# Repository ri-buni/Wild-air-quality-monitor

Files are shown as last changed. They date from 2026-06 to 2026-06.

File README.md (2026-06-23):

# Wild-air-quality-monitor
An air quality monitor I've decided to make because of how bad the air in my city can be sometimes.
It has sht41, sgp40, scd41, PMS5003 as sensors for temperature, humidity, VOC CO2 and PM, 2"42 display and esp32 devkitc

# CAD
Made in Fusion360.

anydesk00012

anydesk00011

anydesk00013

# PCB
Made in KiCad.

Schematic:

anydesk00009

PCB:

anydesk00010

# Firmware was made by Claude Code

Display looks like this:

Screenshot (24)

# BOM

| Item | Description | Qty | Unit Price | Line Total | Source |
|---|---|---|---|---|---|
| PCB | Custom 2-layer PCB | 1 | $12.00 | $12.00 | [JLCPCB](https://jlcpcb.com/) |
| ESP32-S3 DevKitC | MCU dev board | 1 | $5.00 | $5.00 | [AliExpress](https://aliexpress.ru/item/1005007820190456.html?sku_id=12000058365460928) |
| 2.42" OLED | 128x64 SSD1309, I2C/SPI | 1 | $12.00 | $12.00 | [AliExpress](https://aliexpress.ru/item/4000002579405.html?sku_id=12000037978104081) |
| SGP40 | VOC gas sensor module | 1 | $5.00 | $5.00 | [AliExpress](https://aliexpress.ru/item/1005008380047927.html?sku_id=12000056592935021) |
| SCD41 | CO2 + temp/humidity sensor | 1 | $14.00 | $14.00 | [AliExpress](https://aliexpress.ru/item/1005010621571588.html?sku_id=12000053002326414) |
| SHT41 | Temp/humidity sensor | 1 | $1.50 | $1.50 | [AliExpress](https://aliexpress.ru/item/1005008842184215.html?sku_id=12000057743184144) |
| Li-ion battery | 500mAh 3.7V (502535) | 1 | $5.10 | $5.10 | [AliExpress](https://aliexpress.ru/item/1005006462526013.html?sku_id=12000037283411655) |
| TP4056 | Li-ion charger module | 1 | $0.50 | $0.50 | [AliExpress](https://aliexpress.ru/item/32453058256.html?sku_id=12000052763412620) |
| PMS5003 | Laser PM2.5 sensor | 1 | $13.20 | $13.20 | [AliExpress](https://aliexpress.ru/item/32772775425.html?sku_id=12000027208101193) |
| **GRAND TOTAL** |  |  |  | **$68.30** |  |

# Details:

I've used this tutorial as a reference: https://howtomechatronics.com/projects/diy-air-quality-monitor-pm2-5-co2-voc-ozone-temp-hum-arduino-meter/

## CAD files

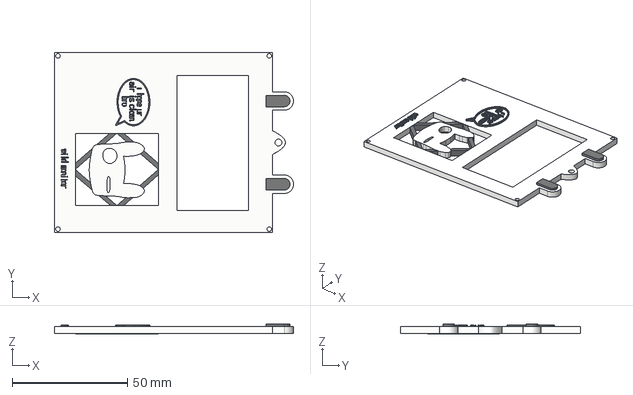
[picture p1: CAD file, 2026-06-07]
Production/TopPart wild monitor.step
103.5 x 78.0 x 4.40 mm

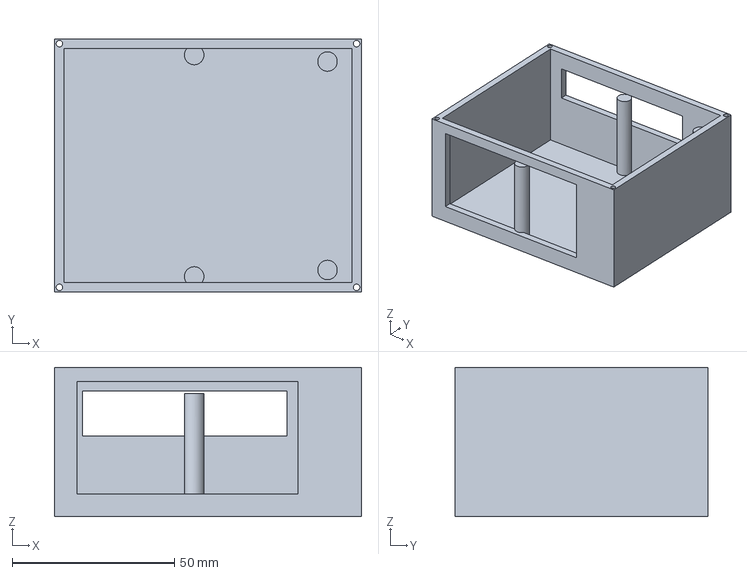
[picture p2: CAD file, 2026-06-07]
Production/BottomPart wild monitor.step
94.5 x 78.0 x 46.0 mm

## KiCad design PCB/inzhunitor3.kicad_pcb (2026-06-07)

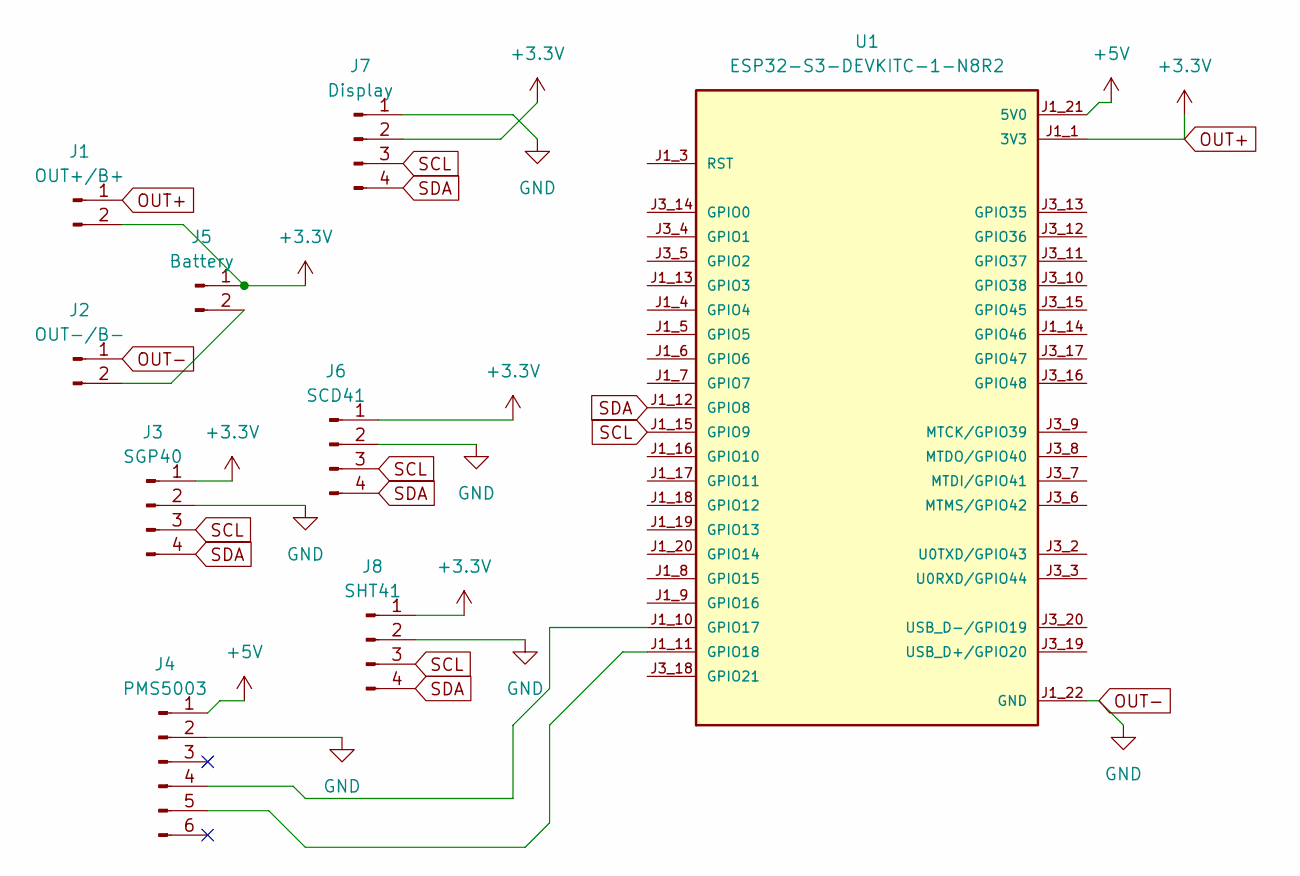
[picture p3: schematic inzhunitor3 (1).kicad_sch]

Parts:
J1: OUT+/B+; PinHeader_1x02_P2.54mm_Vertical
J2: OUT-/B-; PinHeader_1x02_P2.54mm_Vertical
J3: SGP40; PinHeader_1x04_P2.54mm_Vertical
J4: PMS5003; PinHeader_1x06_P2.54mm_Vertical
J5: Battery; PinHeader_1x02_P2.54mm_Vertical
J6: SCD41; PinHeader_1x04_P2.54mm_Vertical
J7: Display; PinHeader_1x04_P2.54mm_Vertical
J8: SHT41; PinHeader_1x04_P2.54mm_Vertical
U1: ESP32-S3-DEVKITC-1-N8R2; XCVR_ESP32-S3-DEVKITC-1-N8R2; PARTREV V1

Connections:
+5V: J4.1, U1.J1_21 (5V0)
unnamed: J2.2, J5.2
unnamed: J4.4, U1.J1_10 (GPIO17)
unnamed: J4.5, U1.J1_11 (GPIO18)
OUT+: J1.1, J1.2, J3.1, J5.1, J6.1, J7.2, J8.1, U1.J1_1 (3V3), U1.J1_2 (3V3)
OUT-: J2.1, J3.2, J4.2, J6.2, J7.1, J8.2, U1.J1_22 (GND), U1.J3_1 (GND), U1.J3_21 (GND), U1.J3_22 (GND)
SCL: J3.3, J6.3, J7.3, J8.3, U1.J1_15 (GPIO9)
SDA: J3.4, J6.4, J7.4, J8.4, U1.J1_12 (GPIO8)

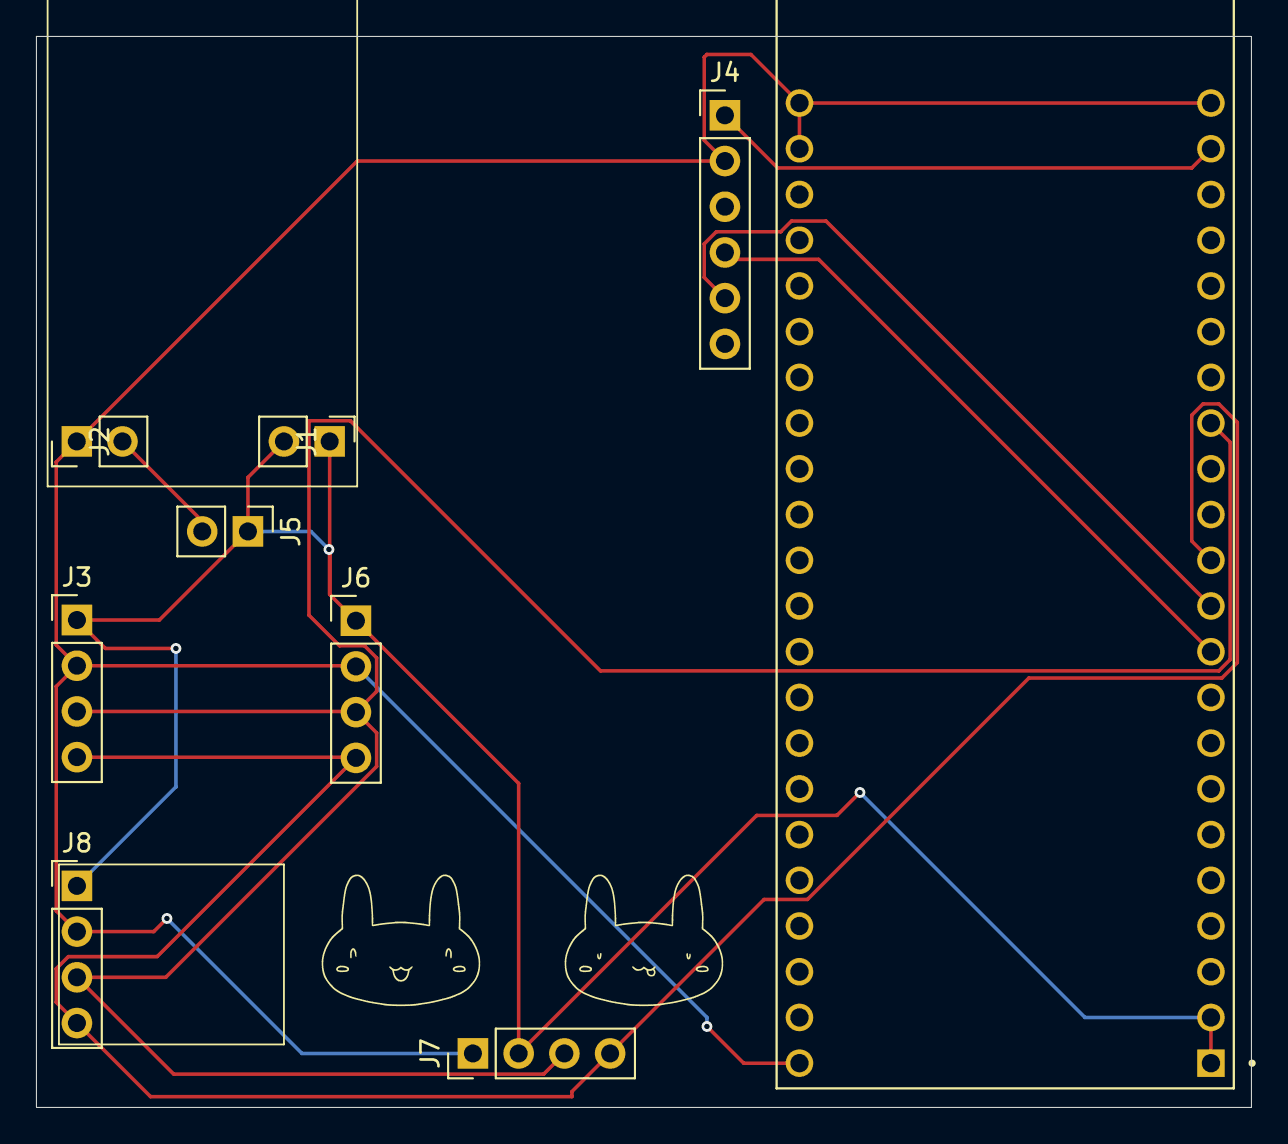
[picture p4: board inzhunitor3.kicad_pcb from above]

Board: 2 copper layers, 67.5 x 59.5 mm, 9 parts (0 on the bottom side), 8 nets.

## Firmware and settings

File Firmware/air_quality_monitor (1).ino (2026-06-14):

/*
 * Air Quality Monitor - ESP32-S3 DevKitC
 * ---------------------------------------
 * SCD41   -> CO2
 * SHT41   -> Temperature / Humidity (also feeds SGP40 compensation)
 * SGP40   -> VOC Index (via Sensirion Gas Index Algorithm)
 * PMS5003 -> PM1.0 / PM2.5 / PM10 (UART, NOT I2C)
 * Display: SSD1306/SSD1309 128x64 OLED over I2C
 * Power: TP4056 + Li-ion (charging handled by TP4056 hardware)
 *
 * Libraries (Arduino Library Manager):
 *   - Sensirion I2C SCD4x
 *   - Sensirion I2C SHT4x
 *   - Sensirion I2C SGP40
 *   - Sensirion Gas Index Algorithm
 *   - U8g2
 *
 * Wiring (I2C): SCD41 / SHT41 / SGP40 / OLED share one bus.
 *   SDA = GPIO8, SCL = GPIO9 (ESP32-S3 DevKitC defaults)
 *   Addresses: SCD41 0x62 | SHT41 0x44 | SGP40 0x59 | OLED 0x3C
 *
 * Wiring (PMS5003 UART, 5V VCC, 3.3V logic - safe for ESP32-S3 RX):
 *   PMS5003 TX (pin 5) -> ESP32 GPIO17 (PMS_RX)
 *   PMS5003 RX (pin 4) -> ESP32 GPIO18 (PMS_TX, optional - for sleep/wake cmds)
 *   PMS5003 VCC -> 5V    GND -> GND
 *   SET / RESET left floating (internal pull-ups keep the sensor running)
 */

#include <Arduino.h>
#include <Wire.h>
#include <U8g2lib.h>
#include <SensirionI2cScd4x.h>
#include <SensirionI2cSht4x.h>
#include <SensirionI2CSgp40.h>
#include <VOCGasIndexAlgorithm.h>

// ---------- I2C pins (ESP32-S3 DevKitC defaults) ----------
#define I2C_SDA 8
#define I2C_SCL 9

// ---------- PMS5003 UART (Serial1) ----------
#define PMS_RX  17   // <- PMS5003 TX
#define PMS_TX  18   // -> PMS5003 RX (optional)
#define PMS_BAUD 9600
#define PMS_FRAME_LEN 32
HardwareSerial PmsSerial(1);

// ---------- Sampling ----------
const uint32_t SAMPLE_INTERVAL_MS = 1000;   // SGP40 must be fed at a CONSTANT 1 Hz
const float    DEFAULT_TEMP_C     = 25.0f;
const float    DEFAULT_RH         = 50.0f;

// ---------- Objects ----------
U8G2_SSD1306_128X64_NONAME_F_HW_I2C u8g2(U8G2_R0, U8X8_PIN_NONE);
// For a true SSD1309 panel, swap the line above for:
// U8G2_SSD1309_128X64_NONAME0_F_HW_I2C u8g2(U8G2_R0, U8X8_PIN_NONE);

SensirionI2cScd4x scd41;
SensirionI2cSht4x sht41;
SensirionI2CSgp40 sgp40;
VOCGasIndexAlgorithm vocAlgorithm;   // default 1 Hz sampling interval

// ---------- Shared state ----------
float    g_temp = DEFAULT_TEMP_C;
float    g_rh   = DEFAULT_RH;
uint16_t g_co2  = 0;
int32_t  g_voc  = 0;
uint16_t g_pm1  = 0;   // PM1.0  (ug/m3, atmospheric)
uint16_t g_pm25 = 0;   // PM2.5  (ug/m3, atmospheric)
uint16_t g_pm10 = 0;   // PM10   (ug/m3, atmospheric)
bool     g_scdReady = false;
bool     g_pmReady  = false;

uint32_t lastSample = 0;

// =====================================================================
//  Helpers
// =====================================================================
static void haltWithError(const char* msg) {
  Serial.println(msg);
  u8g2.clearBuffer();
  u8g2.setFont(u8g2_font_6x12_tf);
  u8g2.drawStr(0, 12, "Init error:");
  u8g2.drawStr(0, 28, msg);
  u8g2.sendBuffer();
  while (true) delay(1000);
}

// Status levels: 0 = noice, 1 = okei, 2 = nah, 3 = Xtreme
uint8_t co2Level(uint16_t c) {
  if (c == 0)    return 0;
  if (c < 800)   return 0;
  if (c < 1200)  return 1;
  if (c < 1600)  return 2;
  return 3;
}
uint8_t vocLevel(int32_t v) {
  if (v < 100) return 0;
  if (v < 200) return 1;
  if (v < 300) return 2;
  return 3;
}
// PM2.5 ug/m3, loosely following US EPA 24h AQI breakpoints
uint8_t pm25Level(uint16_t p) {
  if (p <= 12)  return 0;   // good
  if (p <= 35)  return 1;   // moderate
  if (p <= 55)  return 2;   // unhealthy for sensitive
  return 3;                 // unhealthy+
}
const char* levelWord(uint8_t lvl) {
  switch (lvl) { case 0: return "noice";  case 1: return "okei";
                 case 2: return "nah";    default: return "Xtreme"; }
}

// Map CO2 ppm -> bar fill width (0..maxw), range 400..1600 ppm
uint8_t co2BarWidth(uint16_t c, uint8_t maxw) {
  if (c < 400) c = 400;
  long w = (long)(c - 400) * maxw / 1200;
  if (w > maxw) w = maxw;
  return (uint8_t)w;
}

// ---------------------------------------------------------------------
// Bunny mascot (earless). Drawn from primitives in a ~22x26 box whose
// top-left is (x, y). The face is symmetric about its vertical center.
// Expression changes with the air-quality level:
//   0 noice  -> ^ ^ happy eyes, smile
//   1 okei   -> o o dot eyes, flat mouth
//   2 nah    -> closed eyes (— —), flat mouth
//   3 Xtreme -> x x eyes, frown
// All strokes use the current draw color (set to 1/white by caller).
void drawBunny(uint8_t x, uint8_t y, uint8_t lvl) {
  // Head: rounded box, vertically roomy since there are no ears
  uint8_t hx = x + 2, hy = y + 4, hw = 18, hh = 18;
  u8g2.drawRFrame(hx, hy, hw, hh, 5);

  // Symmetry axis of the head
  uint8_t cx = hx + hw / 2;        // center column
  uint8_t ey = hy + 7;             // eye row
  uint8_t eo = 4;                  // eye offset from center (mirrored)
  uint8_t lx = cx - eo;            // left eye center
  uint8_t rx = cx + eo;            // right eye center

  if (lvl == 0) {
    // ^ ^ happy eyes (mirrored chevrons)
    u8g2.drawLine(lx - 2, ey, lx, ey - 2);
    u8g2.drawLine(lx, ey - 2, lx + 2, ey);
    u8g2.drawLine(rx - 2, ey, rx, ey - 2);
    u8g2.drawLine(rx, ey - 2, rx + 2, ey);
  } else if (lvl == 1) {
    // round dot eyes
    u8g2.drawDisc(lx, ey - 1, 1);
    u8g2.drawDisc(rx, ey - 1, 1);
  } else if (lvl == 2) {
    // closed eyes: short horizontal lines
    u8g2.drawHLine(lx - 2, ey - 1, 5);
    u8g2.drawHLine(rx - 2, ey - 1, 5);
  } else {
    // x x eyes (mirrored)
    u8g2.drawLine(lx - 1, ey - 2, lx + 1, ey);
    u8g2.drawLine(lx - 1, ey, lx + 1, ey - 2);
    u8g2.drawLine(rx - 1, ey - 2, rx + 1, ey);
    u8g2.drawLine(rx - 1, ey, rx + 1, ey - 2);
  }

  // Nose (on the axis) + mouth (symmetric about the axis)
  uint8_t ny = hy + 12;
  u8g2.drawPixel(cx, ny);
  if (lvl == 0) {
    // smile
    u8g2.drawLine(cx - 3, ny + 1, cx, ny + 3);
    u8g2.drawLine(cx, ny + 3, cx + 3, ny + 1);
  } else if (lvl == 3) {
    // frown
    u8g2.drawLine(cx - 3, ny + 3, cx, ny + 1);
    u8g2.drawLine(cx, ny + 1, cx + 3, ny + 3);
  } else {
    // flat mouth, centered
    u8g2.drawHLine(cx - 2, ny + 2, 5);
  }
}

// =====================================================================
//  Sensor reads
// =====================================================================
void readSht41() {
  float t, rh;
  uint16_t err = sht41.measureHighPrecision(t, rh);
  if (!err) {
    g_temp = t;
    g_rh   = rh;
  }
}

void readScd41() {
  bool dataReady = false;
  if (scd41.getDataReadyStatus(dataReady) == 0 && dataReady) {
    uint16_t co2;
    float t, rh;   // SCD41 also reports T/RH; we keep only CO2 per the sensor split
    if (scd41.readMeasurement(co2, t, rh) == 0 && co2 != 0) {
      g_co2 = co2;
      g_scdReady = true;
    }
  }
}

void readSgp40() {
  // Convert SHT41 T/RH into SGP40 compensation ticks
  uint16_t rhTicks   = (uint16_t)((g_rh * 65535) / 100.0f + 0.5f);
  uint16_t tempTicks = (uint16_t)(((g_temp + 45) * 65535) / 175.0f + 0.5f);

  uint16_t sraw = 0;
  uint16_t err = sgp40.measureRawSignal(rhTicks, tempTicks, sraw);
  if (!err) {
    g_voc = vocAlgorithm.process((int32_t)sraw);
  }
}

// PMS5003 frame: 0x42 0x4D | len(2) | 13x uint16 data | checksum(2).
// We read non-blocking; the sensor streams a frame roughly every ~1 s in
// active mode. Returns true when a valid checksummed frame was parsed.
bool readPms5003() {
  bool gotFrame = false;
  // Drain whatever is buffered this tick; keep only the freshest valid frame.
  while (PmsSerial.available() >= PMS_FRAME_LEN) {
    // Sync to start byte 0x42
    if (PmsSerial.peek() != 0x42) { PmsSerial.read(); continue; }

    uint8_t buf[PMS_FRAME_LEN];
    if (PmsSerial.readBytes(buf, PMS_FRAME_LEN) != PMS_FRAME_LEN) break;
    if (buf[1] != 0x4D) continue;   // second header byte must be 0x4D

    // Verify checksum: sum of bytes [0..29] == bytes[30..31]
    uint16_t sum = 0;
    for (uint8_t i = 0; i < 30; i++) sum += buf[i];
    uint16_t chk = ((uint16_t)buf[30] << 8) | buf[31];
    if (sum != chk) continue;       // corrupt frame, skip

    // Atmospheric-environment concentrations (bytes 12..17)
    g_pm1  = ((uint16_t)buf[12] << 8) | buf[13];
    g_pm25 = ((uint16_t)buf[14] << 8) | buf[15];
    g_pm10 = ((uint16_t)buf[16] << 8) | buf[17];
    g_pmReady = true;
    gotFrame = true;
  }
  return gotFrame;
}

// =====================================================================
//  Display
// =====================================================================
void draw() {
  char buf[24];
  u8g2.clearBuffer();

  // ---- Header bar (white) with title + small status pill ----
  uint8_t overall = max(max(co2Level(g_co2), vocLevel(g_voc)), pm25Level(g_pm25));
  u8g2.setDrawColor(1);
  u8g2.drawBox(0, 0, 128, 14);

  u8g2.setFont(u8g2_font_logisoso16_tr);  // header in the logisoso family
  u8g2.setDrawColor(0);                    // black text on white bar
  u8g2.drawStr(3, 13, "ri's grade");

  // ---- Hero: bunny mascot + big status word ----
  u8g2.setDrawColor(1);
  drawBunny(2, 16, overall);

  const char* word = levelWord(overall);
  u8g2.setFont(u8g2_font_helvB14_tr);   // bold; "Xtreme" fits left of the value column
  u8g2.drawStr(28, 38, word);

  // ---- CO2 + PM2.5 as small labeled values on the right column ----
  u8g2.setFont(u8g2_font_5x8_tr);
  // CO2
  if (g_scdReady) snprintf(buf, sizeof(buf), "CO2 %u", g_co2);
  else            strcpy(buf, "CO2 --");
  u8g2.drawStr(127 - u8g2.getStrWidth(buf), 25, buf);
  // PM2.5
  if (g_pmReady)  snprintf(buf, sizeof(buf), "PM %u", g_pm25);
  else            strcpy(buf, "PM --");
  u8g2.drawStr(127 - u8g2.getStrWidth(buf), 35, buf);

  // ---- CO2 level bar with threshold ticks (800 / 1200 / 1600 ppm) ----
  u8g2.drawVLine(33, 44, 2);
  u8g2.drawVLine(64, 44, 2);
  u8g2.drawVLine(95, 44, 2);
  u8g2.drawFrame(0, 46, 128, 6);
  uint8_t bw = co2BarWidth(g_scdReady ? g_co2 : 0, 124);
  if (bw > 0) u8g2.drawBox(2, 48, bw, 2);

  // ---- Footer: temp | humidity | VOC ----
  u8g2.drawVLine(43, 54, 9);
  u8g2.drawVLine(85, 54, 9);

  // thermometer icon
  u8g2.drawVLine(4, 55, 5);
  u8g2.drawDisc(4, 61, 1);
  u8g2.setFont(u8g2_font_5x8_tr);
  snprintf(buf, sizeof(buf), "%.1f", g_temp);
  u8g2.drawStr(9, 62, buf);
  u8g2.drawStr(9 + u8g2.getStrWidth(buf), 62, "\xb0");  // degree

  // droplet icon
  u8g2.drawDisc(48, 60, 2);
  u8g2.drawTriangle(48, 55, 46, 59, 50, 59);
  snprintf(buf, sizeof(buf), "%.0f%%", g_rh);
  u8g2.drawStr(53, 62, buf);

  // VOC
  snprintf(buf, sizeof(buf), "VOC %ld", (long)g_voc);
  u8g2.drawStr(88, 62, buf);

  u8g2.sendBuffer();
}

// =====================================================================
//  Setup / Loop
// =====================================================================
void setup() {
  Serial.begin(115200);
  delay(200);

  Wire.begin(I2C_SDA, I2C_SCL);
  Wire.setClock(100000);   // 100 kHz is safe for all four devices

  // PMS5003 on UART1 (active mode by default - it just streams frames)
  PmsSerial.begin(PMS_BAUD, SERIAL_8N1, PMS_RX, PMS_TX);

  // Display splash
  u8g2.begin();
  u8g2.setFont(u8g2_font_6x12_tf);
  u8g2.clearBuffer();
  u8g2.drawStr(0, 12, "ri's grade");
  u8g2.drawStr(0, 30, "Warming up...");
  u8g2.sendBuffer();

  char errMsg[64];
  uint16_t err;

  // --- SHT41 ---
  sht41.begin(Wire, SHT41_I2C_ADDR_44);
  sht41.softReset();
  delay(20);

  // --- SCD41 ---
  scd41.begin(Wire, SCD41_I2C_ADDR_62);
  scd41.wakeUp();
  scd41.stopPeriodicMeasurement();   // ensure a clean state
  delay(500);
  scd41.reinit();
  delay(20);
  err = scd41.startPeriodicMeasurement();   // new reading ~every 5 s
  if (err) {
    errorToString(err, errMsg, sizeof(errMsg));
    haltWithError(errMsg);
  }

  // --- SGP40 ---
  sgp40.begin(Wire);
  uint16_t testRaw = 0;
  err = sgp40.measureRawSignal(0x8000, 0x6666, testRaw);  // ping with defaults
  if (err) {
    errorToString(err, errMsg, sizeof(errMsg));
    Serial.print("SGP40 warning: ");
    Serial.println(errMsg);
  }

  lastSample = millis();
}

void loop() {
  uint32_t now = millis();
  if (now - lastSample >= SAMPLE_INTERVAL_MS) {
    lastSample += SAMPLE_INTERVAL_MS;

    readSht41();   // 1) temperature + humidity
    readScd41();   // 2) CO2 (updates ~every 5 s)
    readSgp40();   // 3) VOC, compensated by SHT41 T/RH
    readPms5003(); // 4) PM1.0 / PM2.5 / PM10 (UART stream)

    draw();

    Serial.printf("CO2=%u ppm  VOC=%ld  T=%.2f C  RH=%.1f %%  "
                  "PM1=%u PM2.5=%u PM10=%u ug/m3\n",
                  g_co2, (long)g_voc, g_temp, g_rh,
                  g_pm1, g_pm25, g_pm10);
  }
}
